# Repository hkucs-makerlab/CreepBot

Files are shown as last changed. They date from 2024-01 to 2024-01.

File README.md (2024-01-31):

# CreepBot For ROS
CreepBot - 3D Printed Mini Quadruped Robot For [ROS](https://ros.org/) Programming Workshops




## Introduction

CreepBot is a low cost 3D printed mini quadruped robot. The firmware implements ROSSerial protocol to publish and subscribe topics 
via Bluetooth SPP to support ROS framework. It is designed and intended for students to practice writing ROS packages and learn 3D printing to make robot.

## Robot Firmware

Download [AVRDUDESS](https://blog.zakkemble.net/avrdudess-a-gui-for-avrdude/) to upload robot firmware

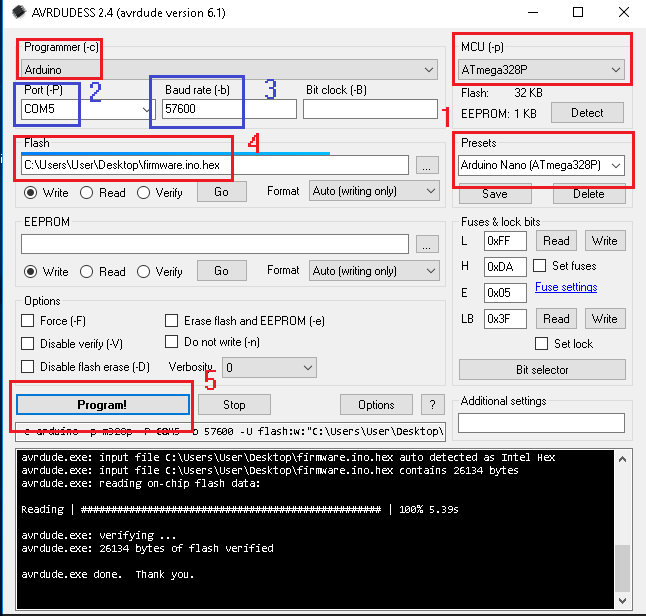
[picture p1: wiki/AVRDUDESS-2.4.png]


## Electronic Components
### Robot
<ol>
  <li><a href="https://youtu.be/woJ8mIrGqf4?si=4_YU_JZL80stXMVt" target=_blank>HuaDuino</a> - Arduino Nano Compatible Board with Lithium Battery Power Up & Charging</li>
  <li>8 x MG90s servos</li>
  <li>HC-SR04 Ultrasonic sensor (for no camera head version)</li>
  <li>HC-04/05 or compatible Bluetooth SPP module, set baud rate to 38400
  <li>CC2541 Bluetooth LE module (optional)</li>
  <li>Buzzer</li>
  <li>18650 lithium battery with x2.54 connector</li>
  <li>Some M2x6/M2x10 tapping screws</li>
  <li>Some dupoint wires</li>
</ol>

### Camera head
  <ol>
    <li>ESP32cam</li>
    <li>Some dupoint wires</li>
    <li>firmware - https://github.com/sunfounder/ai-camera-firmware</li>
  </ol>

## Video of How to Make a CreepBot
### Camera Head Version
how to make a creepbot (https://www.youtube.com/watch?v=wkgwL2prcCM)

creepbot demo (https://www.youtube.com/watch?v=PgKKCWNNcuk)

### Ultrasonic Sensor Head Version
how to make a creepbot (https://www.youtube.com/watch?v=LDjwKNZhbA8)

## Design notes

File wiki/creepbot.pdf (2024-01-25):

## CreepBot - Low Cost 3D Printed Robot Kit for STEM

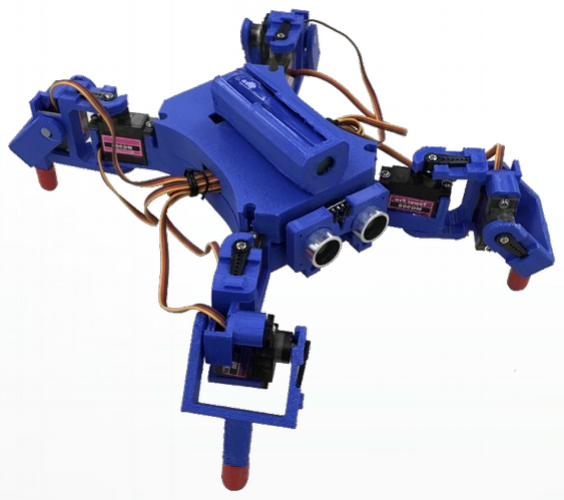
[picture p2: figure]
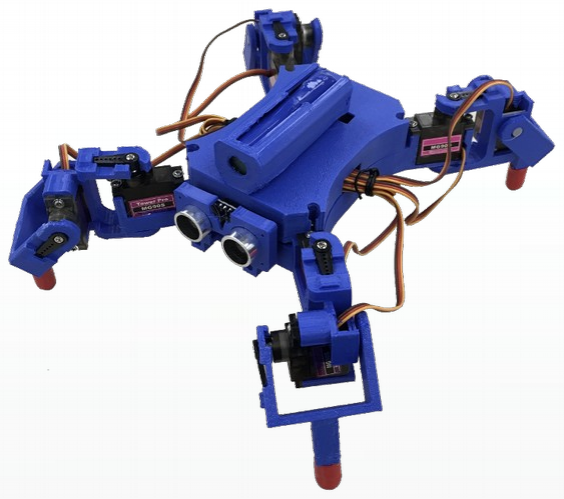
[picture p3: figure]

by David Lee

## Introduction

- Motiviation of design
– | Similar robot kit in market is expensive;
| ● We want a kit to be affortable to all students
– | 3D printer is cheap;

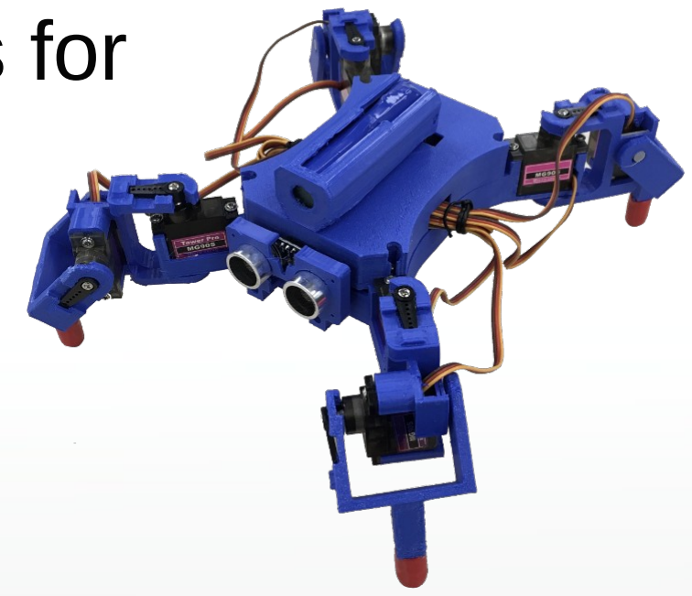
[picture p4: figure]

- As teaching materials for
– | 3D Printing
– | Programming
– | Robotics

## CreepBot

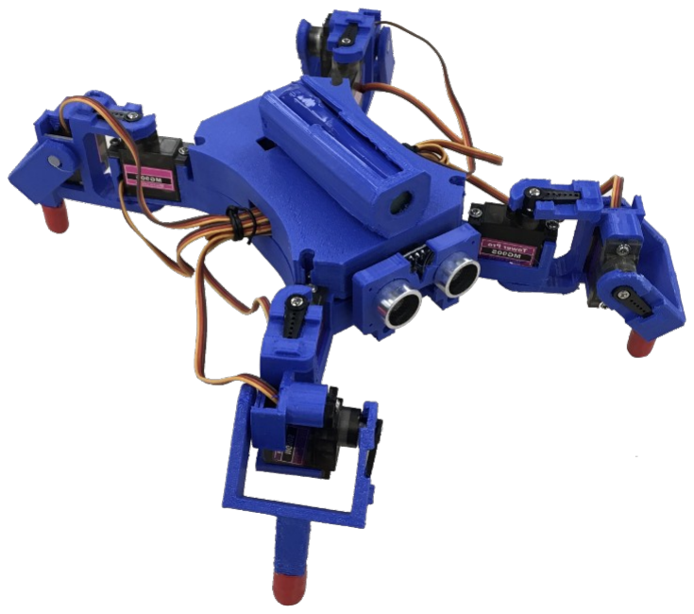
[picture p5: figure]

●

It is a quaduped robot;

●

It is a custom made and lower cost using 3D printed;

●

It is control by the smartphone app
- Commuication Link –
Bluetooth
- Configuration -
1.8 DOF actuators – Servo Motors 2.Ultrasonic sensor
3.Buzzer
4.Bluetooth module

## CreepBot Components

- 3D Print Models – some of examples

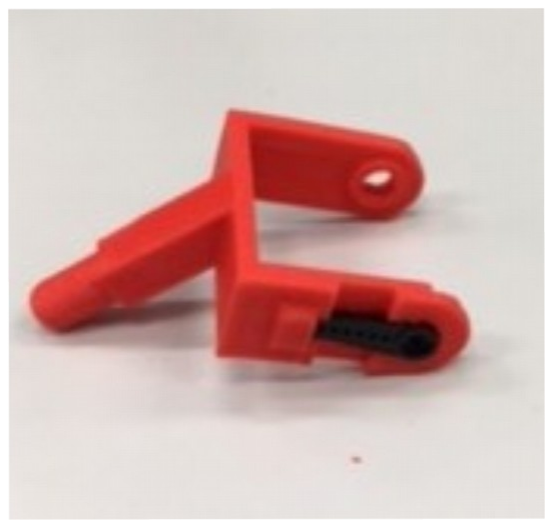
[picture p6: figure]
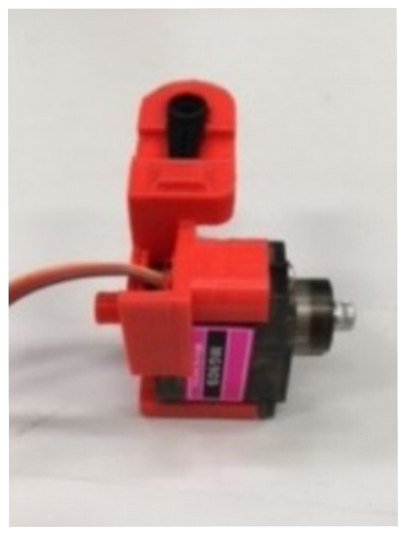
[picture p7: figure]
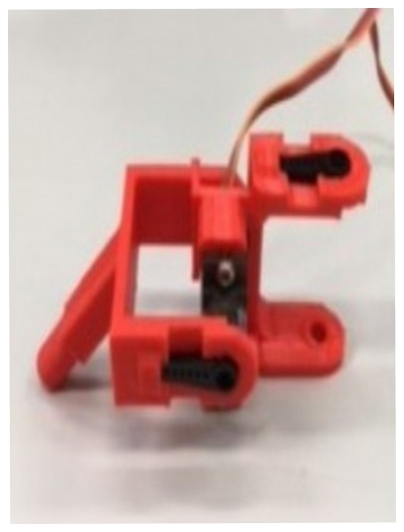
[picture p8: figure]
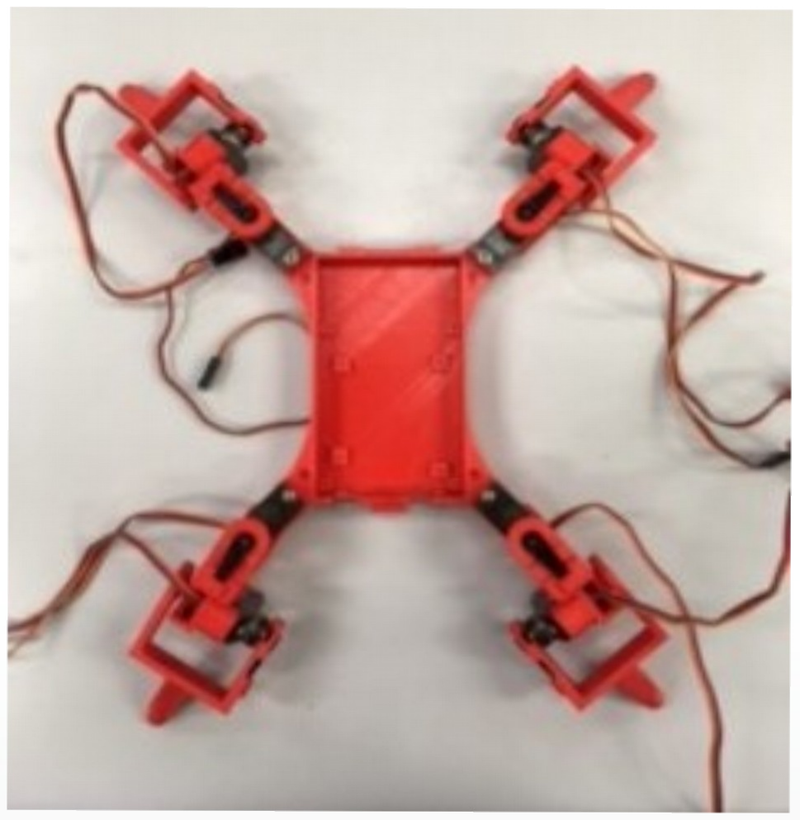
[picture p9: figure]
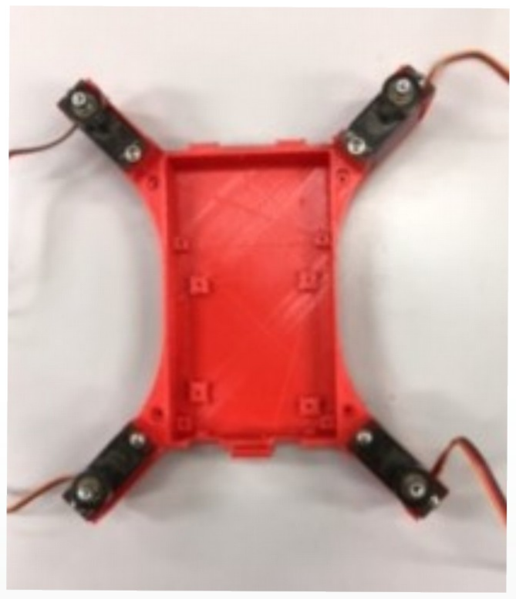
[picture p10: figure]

## CreepBot Components

- MCU board

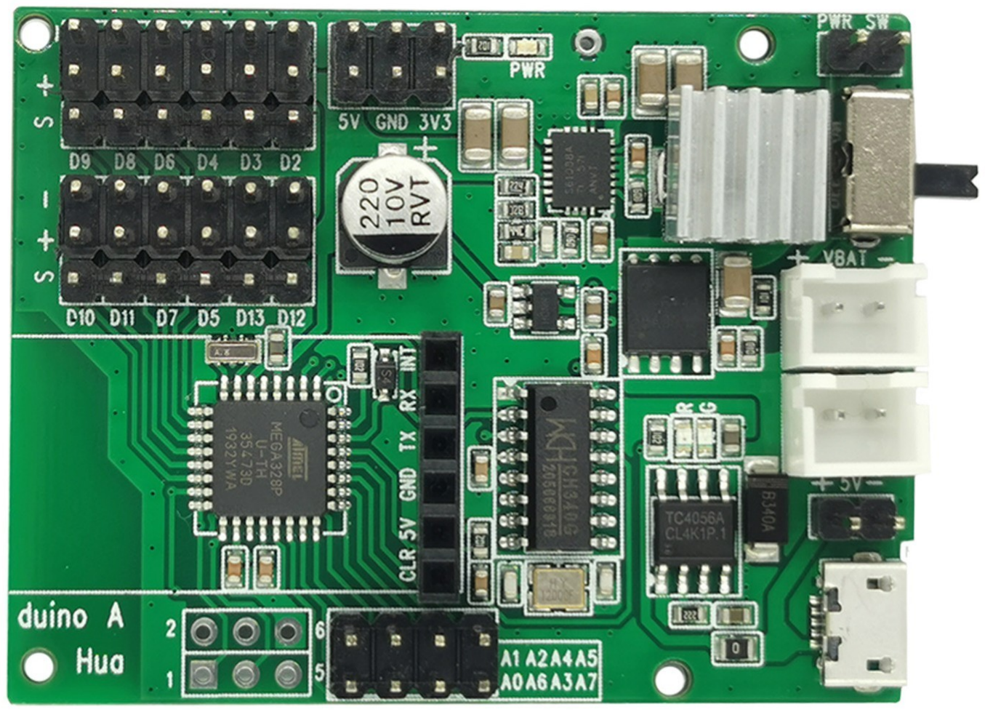
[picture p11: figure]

## CreepBot Components

- Actuators of creepbot - 8 of MG90S servos

Right Front Limb
hip – D9
leg – D8

Right Back Limb
hip – D6
leg – D4

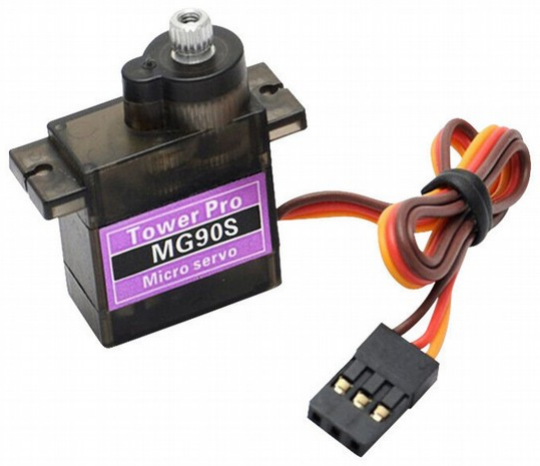
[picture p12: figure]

Wire – Yellow (Signal), VCC(+), GND(-)

Left Front Limb
hip – D10
leg – D11

Left Back Limb
hip – D7
leg – D5

Signal Pins -

## CreepBot Components

- Buzzer

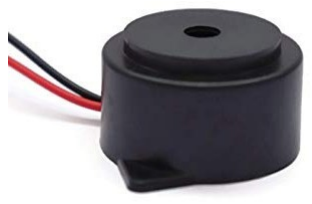
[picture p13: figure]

- Ultrasonic Distant Sensor

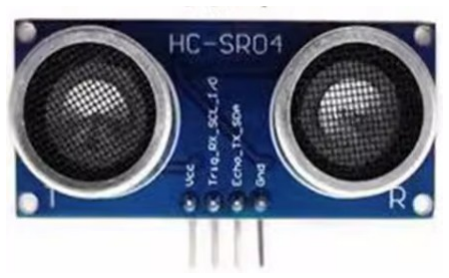
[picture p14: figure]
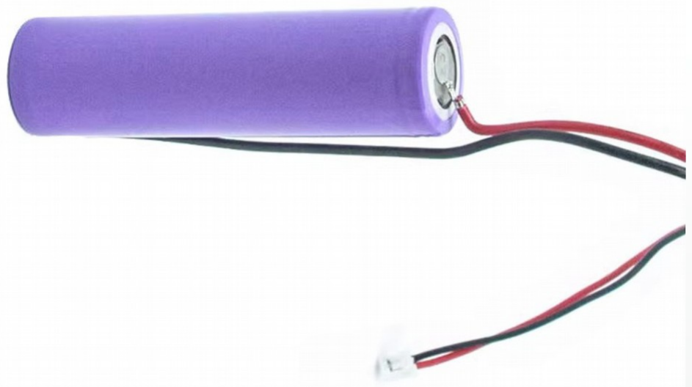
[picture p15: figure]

- 18650 lithium battery

Pins - VCC(+), Trigger(D2), Echo(D3), GND(-)

Pins – Red (A0), Gnd

Pins – Positive, GND(-)

## CreepBot Components

- Bluetooth BLE Module for goBLE smartphone app

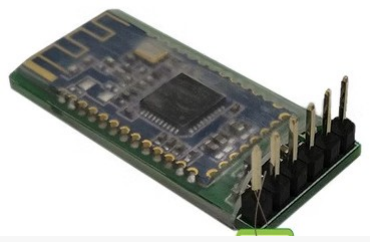
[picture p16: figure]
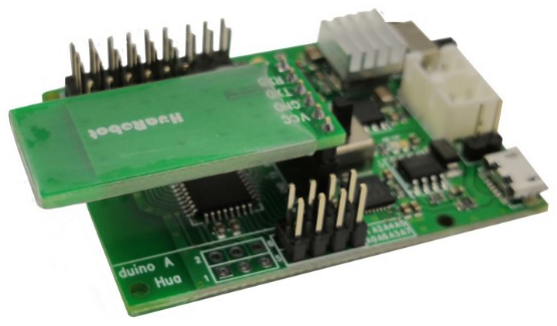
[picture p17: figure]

- To distinguish each module among others, a number is assigned to it, marked on the back;
- A string prefix “BT05-” assoicateed the number form the name of the module e.g

BT05-01; Plugs into 6 pin female connector

## CreepBot - Building Guide

- Video - https://youtu.be/LDjwKNZhbA8

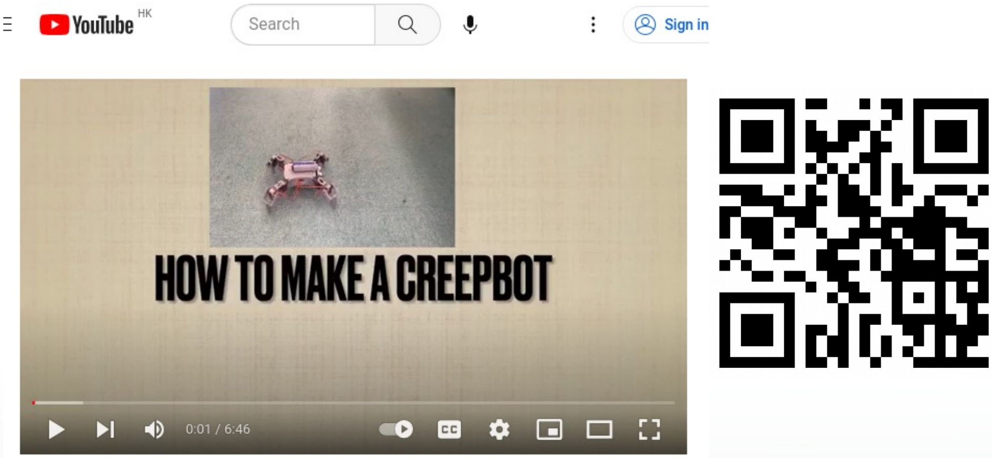
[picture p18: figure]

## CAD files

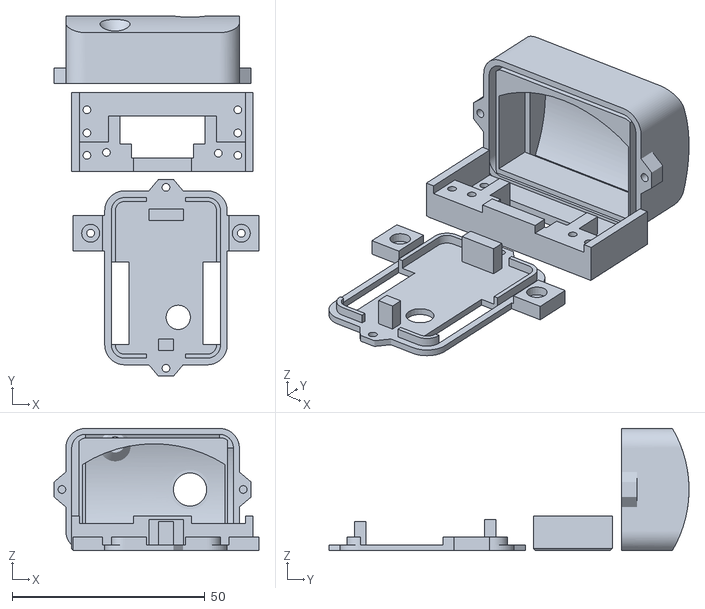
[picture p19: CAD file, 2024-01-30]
stl-models/camera-head.stl
53.0 x 93.3 x 31.7

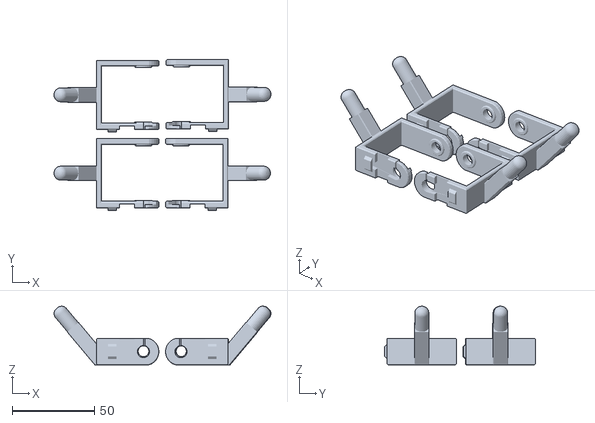
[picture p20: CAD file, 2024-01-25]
stl-models/tibia2.stl
131.7 x 91.3 x 35.6

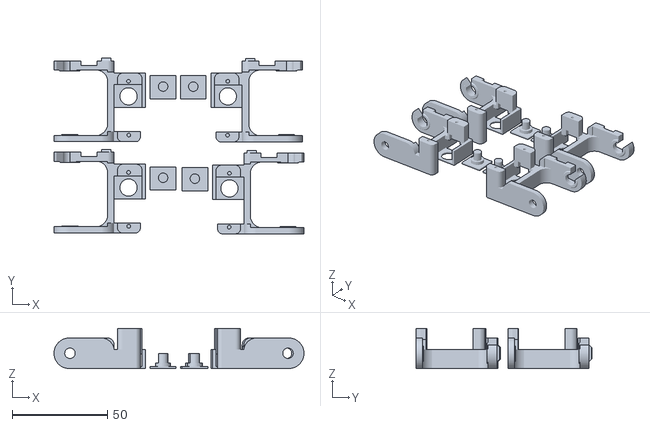
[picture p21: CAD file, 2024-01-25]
stl-models/coxa2.stl
130.9 x 92.0 x 21.0

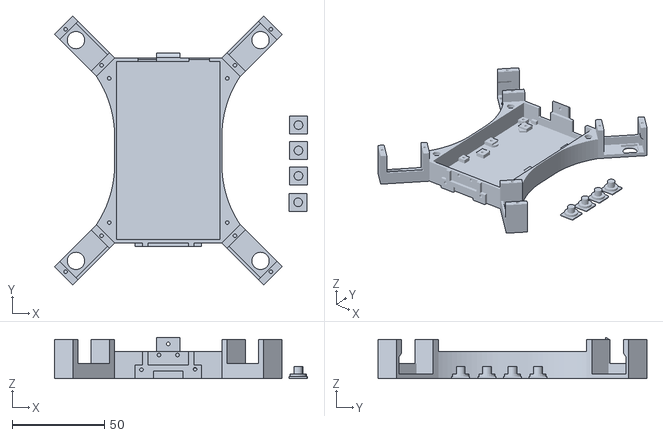
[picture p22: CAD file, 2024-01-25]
stl-models/body_base2.stl
136.8 x 145.3 x 22.2

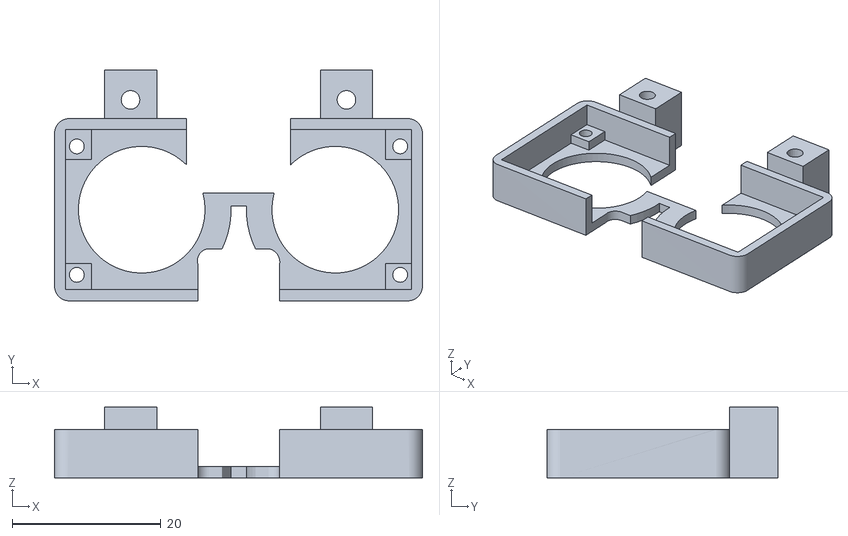
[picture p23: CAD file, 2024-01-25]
stl-models/hc-sr04-holder.stl
49.4 x 31.0 x 9.50

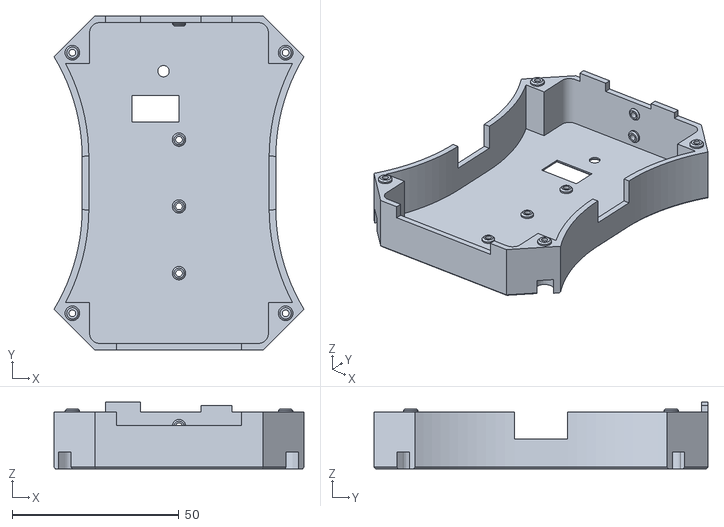
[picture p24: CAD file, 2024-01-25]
stl-models/body_cover2.stl
74.8 x 100.0 x 20.0

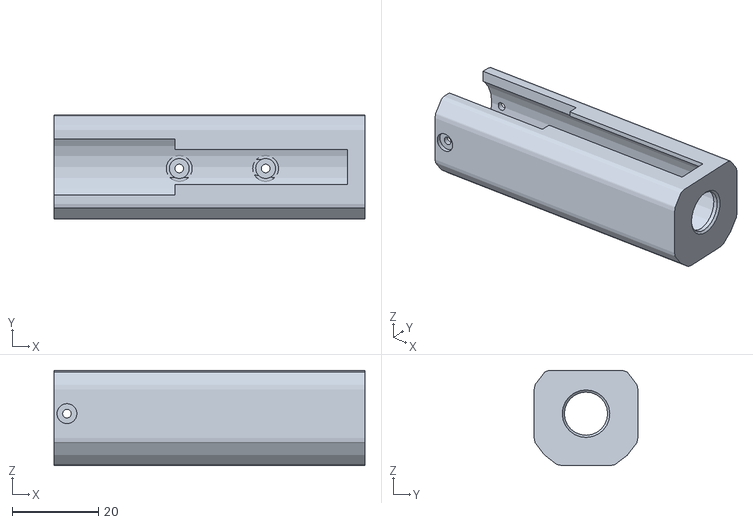
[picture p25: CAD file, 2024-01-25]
stl-models/18650_battery_case.stl
72.0 x 24.0 x 22.0
